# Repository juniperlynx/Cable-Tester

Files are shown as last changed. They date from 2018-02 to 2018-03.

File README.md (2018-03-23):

# Cable-Tester
This is a replacement PCB and software for a cheap commercial cable tester usually sold as the HL-486 (though there are other model numbers, mine is ST-M810).
It improves on the original design by adding beefier drive circuitry and a proper voltage regulator for the microcontroller.

Schematics and PCB layouts are available for both ends. The current revision of the Gerbers is untested but only contains slight variations from the most recently ordered version. Complete BOMs for both the master and remote ends are now available for both ends along with Digikey shoping carts in .csv format. I haven't been able to find a source for the multi-LED standoffs used to space the strand indicator LEDs so I've modeled a part in OpenSCAD. The OpenSCAD source and a rendered .stl file are available but untested at this time.

The original Kicad design files are in "Kicad Files/" and the software source code in "Software/".
If you'd like to build your own use the Gerber files in "Gerbers/" and the BOMs in "BOM/" along with the standoff model in "3D Parts/STL"

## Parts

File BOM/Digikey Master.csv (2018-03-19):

Manufacturer Part Number | Manufacturer | Digi-Key Part Number | Customer Reference | Reference Designator | Packaging | Part Status | Quantity | Unit Price | Extended Price | Quantity Available | Mfg Std Lead Time | Description | RoHS Status | Lead Free Status | REACH Status
SLR-342VR3F | Rohm Semiconductor | 511-1250-ND |  |  | Bulk | Active | 1 | 0.55000 | $0.55 | 44855 | 10 Weeks | LED RED DIFF 3MM ROUND T/H | RoHS Compliant | Lead free | REACH Unaffected
EG2301A | E-Switch | EG1944-ND |  |  | Bulk | Active | 1 | 0.80000 | $0.80 | 4235 | 11 Weeks | SWITCH SLIDE DP3T 200MA 30V | RoHS Compliant | Lead free | REACH Unaffected
5555154-1 | TE Connectivity AMP Connectors | A31440-ND |  |  | Tray | Active | 1 | 1.69000 | $1.69 | 1817 | 17 Weeks | CONN MOD JACK 6P6C R/A SHIELDED | RoHS Compliant | Lead free | Not Available
5555153-1 | TE Connectivity AMP Connectors | A31438-ND |  |  | Tray | Active | 1 | 1.42000 | $1.42 | 10974 | 17 Weeks | CONN MOD JACK 8P8C R/A SHIELDED | RoHS Compliant | Lead free | Not Available
LEDM-2-10 | Essentra Components | RPC4263-ND |  |  | Bulk | Active | 1 | 0.44000 | $0.44 | 5000 | 7 Weeks | LED SPACER 3MM T-1 BLACK 10MM | RoHS Compliant | Lead free | REACH Unaffected
M20-9720345 | Harwin Inc. | 952-1921-ND |  |  | Bulk | Active | 1 | 0.33000 | $0.33 | 1730 | 10 Weeks | 2X3POS DIL VERTICAL PIN HEADER | RoHS Compliant | Lead free | REACH Unaffected
UA78L05ACDR | Texas Instruments | 296-1364-1-ND |  |  | Cut Tape (CT) | Active | 1 | 0.50000 | $0.50 | 19285 | 6 Weeks | IC REG LINEAR 5V 100MA 8SOIC | RoHS Compliant | Lead free | REACH Unaffected
SSL-LX2573SRD | Lumex Opto/Components Inc. | 67-1049-ND |  |  | Bulk | Active | 9 | 0.46000 | $4.14 | 5202 | 12 Weeks | LED RED DIFF 5X2MM RECT T/H | RoHS Compliant | Lead free | REACH Unaffected
ATTINY24A-SSUR | Microchip Technology | ATTINY24A-SSURCT-ND |  |  | Cut Tape (CT) | Active | 1 | 0.76000 | $0.76 | 21974 | 4 Weeks | IC MCU 8BIT 2KB FLASH 14SOIC | RoHS Compliant | Lead free | REACH Unaffected
BSS84PH6433XTMA1 | Infineon Technologies | BSS84PH6433XTMA1CT-ND |  |  | Cut Tape (CT) | Active | 9 | 0.28000 | $2.52 | 31583 | Not Available | MOSFET P-CH 60V 170MA SOT-23 | RoHS Compliant | Lead free | REACH Unaffected
2N7002P,235 | Nexperia USA Inc. | 1727-1865-1-ND |  |  | Cut Tape (CT) | Active | 9 | 0.16000 | $1.44 | 92060 | 26 Weeks | MOSFET N-CH 60V 0.36A SOT-23 | RoHS Compliant | Lead free | REACH Unaffected
1N4448W-TP | Micro Commercial Co | 1N4448WTPMSCT-ND |  |  | Cut Tape (CT) | Active | 9 | 0.14000 | $1.26 | 448109 | 8 Weeks | DIODE GEN PURP 75V 250MA SOD123 | RoHS Compliant | Lead free | REACH Unaffected
CC0805KRX7R8BB104 | Yageo | 311-1141-1-ND |  |  | Cut Tape (CT) | Active | 1 | 0.10000 | $0.10 | 0 | 37 Weeks | CAP CER 0.1UF 25V X7R 0805 | RoHS Compliant | Lead free | REACH Unaffected
CC0805KKX7R8BB105 | Yageo | 311-1456-1-ND |  |  | Cut Tape (CT) | Active | 2 | 0.12000 | $0.24 | 492833 | 19 Weeks | CAP CER 1UF 25V X7R 0805 | RoHS Compliant | Lead free | REACH Unaffected
RC0805JR-0710KL | Yageo | 311-10KARCT-ND |  |  | Cut Tape (CT) | Active | 2 | 0.10000 | $0.20 | 4354256 | 23 Weeks | RES SMD 10K OHM 5% 1/8W 0805 | RoHS Compliant | Lead free | REACH Unaffected
RC0805JR-071KL | Yageo | 311-1.0KARCT-ND |  |  | Cut Tape (CT) | Active | 1 | 0.10000 | $0.10 | 3591832 | 23 Weeks | RES SMD 1K OHM 5% 1/8W 0805 | RoHS Compliant | Lead free | REACH Unaffected
RC0805JR-07200RL | Yageo | 311-200ARCT-ND |  |  | Cut Tape (CT) | Active | 9 | 0.10000 | $0.90 | 459061 | 23 Weeks | RES SMD 200 OHM 5% 1/8W 0805 | RoHS Compliant | Lead free | REACH Unaffected
232 | Keystone Electronics | 36-232-ND |  |  | Bulk | Active | 1 | 0.60000 | $0.60 | 62435 | 6 Weeks | STRAP BATT ECON 9V I STYLE 4"LD | RoHS Compliant | Lead free | REACH Unaffected

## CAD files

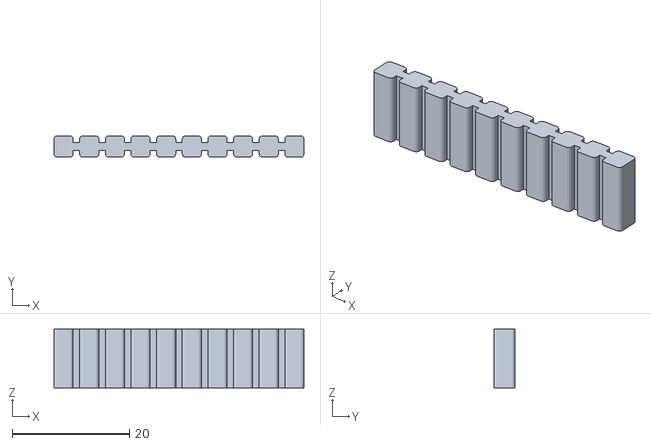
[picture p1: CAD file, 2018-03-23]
3D Parts/STL/LED standoff.stl
42.7 x 3.63 x 10.0

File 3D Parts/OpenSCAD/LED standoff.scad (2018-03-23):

$fn = 30;

// Produces dividers between LEDs, width and length are
// center-to-center for the bounding cylinders so total
// length is length + (edgeradius * 2) and the same for
// width. Height is as given though
module divider(width, length, height, edgeradius) {
    hull() {
        translate([-length/2, width/2, 0]) {
            cylinder(r = edgeradius, h = height);
        }
        translate([-length/2, -width/2, 0]) {
            cylinder(r = edgeradius, h = height);
        }
        translate([length/2, width/2, 0]) {
            cylinder(r = edgeradius, h = height);
        }
        translate([length/2, -width/2, 0]) {
            cylinder(r = edgeradius, h = height);
        }
    }
}
// Produces an LED standoff with the given number of
// spaces, spacing, width (center-to-center) and height.
module standoff(numspaces, spacing, width, voidsize, height){
    divlength = spacing - (voidsize * 2);
    supportwidth = width - voidsize;
    length = (numspaces * spacing) + divlength;
    union() {    
        for(i = [0:numspaces]) {
            translate([i * spacing, 0, 0]) { 
                divider(width, divlength, height, voidsize/2);
            }
        }
        translate([-divlength/2,-supportwidth/2,0]){
            cube([length,supportwidth,height]);
        }
    }
}
// Set parameters. The units here are in millimeters.

// Number of LEDs
numleds = 9;

// Spacing between LEDs
spacing = 4.3815;

// LED pad pitch
width = 2.54;

// LED pad drill diameter (plus some)
voidsize = 1.1;

// Standoff height
height = 10;

// Get part
standoff(numleds, spacing, width, voidsize, height);

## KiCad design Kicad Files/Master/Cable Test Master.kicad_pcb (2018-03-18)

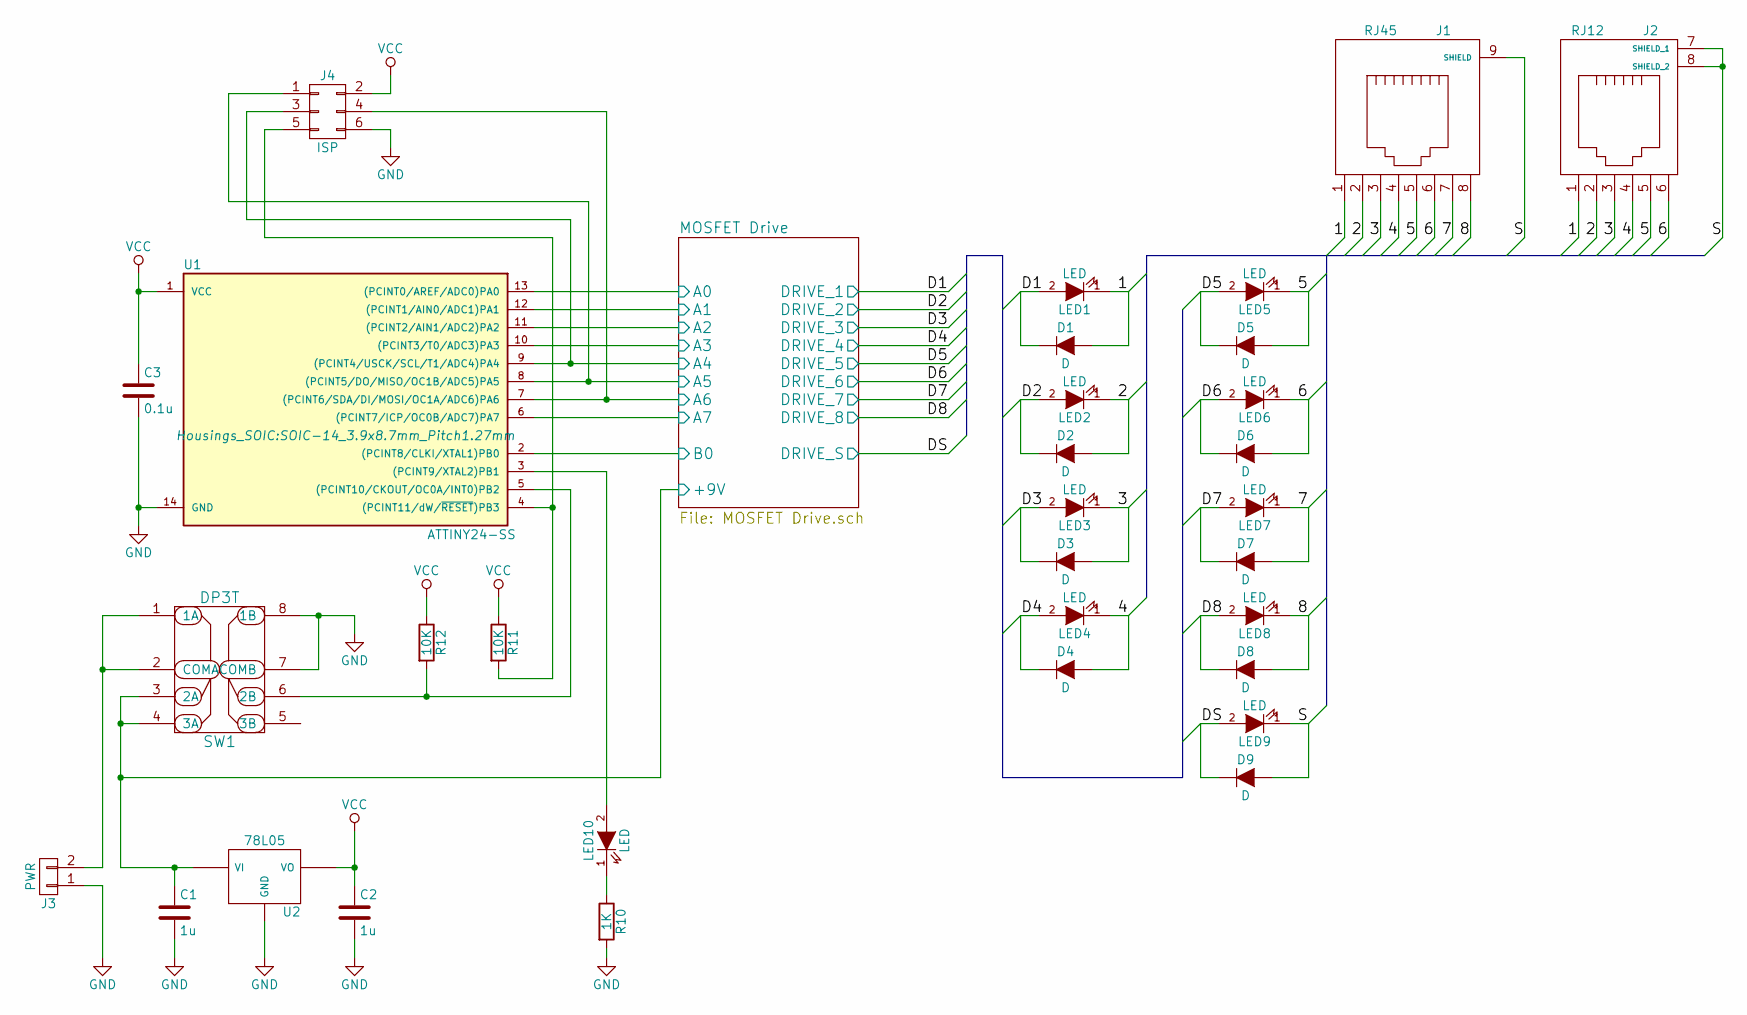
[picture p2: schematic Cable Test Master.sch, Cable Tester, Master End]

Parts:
C1, C2: 1u; C_0805_HandSoldering
C3: 0.1u; C_0805_HandSoldering
D1, D2, D3, D4, D5, D6, D7, D8, D9: D; SOD-123
J1: RJ45; RJ45_SHLD
J2: RJ12; RJ12_SHLD
J3: PWR; Pin_Header_Straight_1x02
J4: ISP; Pin_Header_Straight_2x03
LED1, LED2, LED3, LED4, LED5, LED6, LED7, LED8, LED9, LED10: LED; LED-3MM
R10: 1K; R_0805_HandSoldering
R11, R12: 10K; R_0805_HandSoldering
SW1: DP3T; SW_DP3T_SLIDE
U1: ATTINY24-SS; SOIC-14_3.9x8.7mm_Pitch1.27mm
U2: 78L05; 78L05_SOIC

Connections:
/1: D1.2 (A), J1.1, J2.1, LED1.1 (K)
/2: D2.2 (A), J1.2, J2.2, LED2.1 (K)
/3: D3.2 (A), J1.3, J2.3, LED3.1 (K)
/4: D4.2 (A), J1.4, J2.4, LED4.1 (K)
/5: D5.2 (A), J1.5, J2.5, LED5.1 (K)
/6: D6.2 (A), J1.6, J2.6, LED6.1 (K)
/7: D7.2 (A), J1.7, LED7.1 (K)
/8: D8.2 (A), J1.8, LED8.1 (K)
/MOSFET Drive/+9V: C1.1, SW1.3 (2A), SW1.4 (3A), U2.VI; also elsewhere on the board
/MOSFET Drive/A0: U1.13 ((PCINT0/AREF/ADC0)PA0); also elsewhere on the board
/MOSFET Drive/A1: U1.12 ((PCINT1/AIN0/ADC1)PA1); also elsewhere on the board
/MOSFET Drive/A2: U1.11 ((PCINT2/AIN1/ADC2)PA2); also elsewhere on the board
/MOSFET Drive/A3: U1.10 ((PCINT3/T0/ADC3)PA3); also elsewhere on the board
/MOSFET Drive/A4: J4.3, U1.9 ((PCINT4/USCK/SCL/T1/ADC4)PA4); also elsewhere on the board
/MOSFET Drive/A5: J4.1, U1.8 ((PCINT5/DO/MISO/OC1B/ADC5)PA5); also elsewhere on the board
/MOSFET Drive/A6: J4.4, U1.7 ((PCINT6/SDA/DI/MOSI/OC1A/ADC6)PA6); also elsewhere on the board
/MOSFET Drive/A7: U1.6 ((PCINT7/ICP/OC0B/ADC7)PA7); also elsewhere on the board
/MOSFET Drive/B0: U1.2 ((PCINT8/CLKI/XTAL1)PB0); also elsewhere on the board
/MOSFET Drive/DRIVE_1: D1.1 (K), LED1.2 (A); also elsewhere on the board
/MOSFET Drive/DRIVE_2: D2.1 (K), LED2.2 (A); also elsewhere on the board
/MOSFET Drive/DRIVE_3: D3.1 (K), LED3.2 (A); also elsewhere on the board
/MOSFET Drive/DRIVE_4: D4.1 (K), LED4.2 (A); also elsewhere on the board
/MOSFET Drive/DRIVE_5: D5.1 (K), LED5.2 (A); also elsewhere on the board
/MOSFET Drive/DRIVE_6: D6.1 (K), LED6.2 (A); also elsewhere on the board
/MOSFET Drive/DRIVE_7: D7.1 (K), LED7.2 (A); also elsewhere on the board
/MOSFET Drive/DRIVE_8: D8.1 (K), LED8.2 (A); also elsewhere on the board
/MOSFET Drive/DRIVE_S: D9.1 (K), LED9.2 (A); also elsewhere on the board
/S: D9.2 (A), J1.9 (SHIELD), J2.7 (SHIELD_1), J2.8 (SHIELD_2), LED9.1 (K)
GND: C1.2, C2.2, C3.2, J3.1, J4.6, R10.2, SW1.7 (COMB), SW1.8 (1B), U1.14 (GND), U2.GND; also elsewhere on the board
unnamed: J3.2, SW1.1 (1A), SW1.2 (COMA)
unnamed: J4.5, R11.2, U1.4 ((PCINT11/dW/~RESET~)PB3)
unnamed: LED10.1 (K), R10.1
unnamed: LED10.2 (A), U1.3 ((PCINT9/XTAL2)PB1)
unnamed: R12.2, SW1.6 (2B), U1.5 ((PCINT10/CKOUT/OC0A/INT0)PB2)
VCC: C2.1, C3.1, J4.2, R11.1, R12.1, U1.1 (VCC), U2.VO

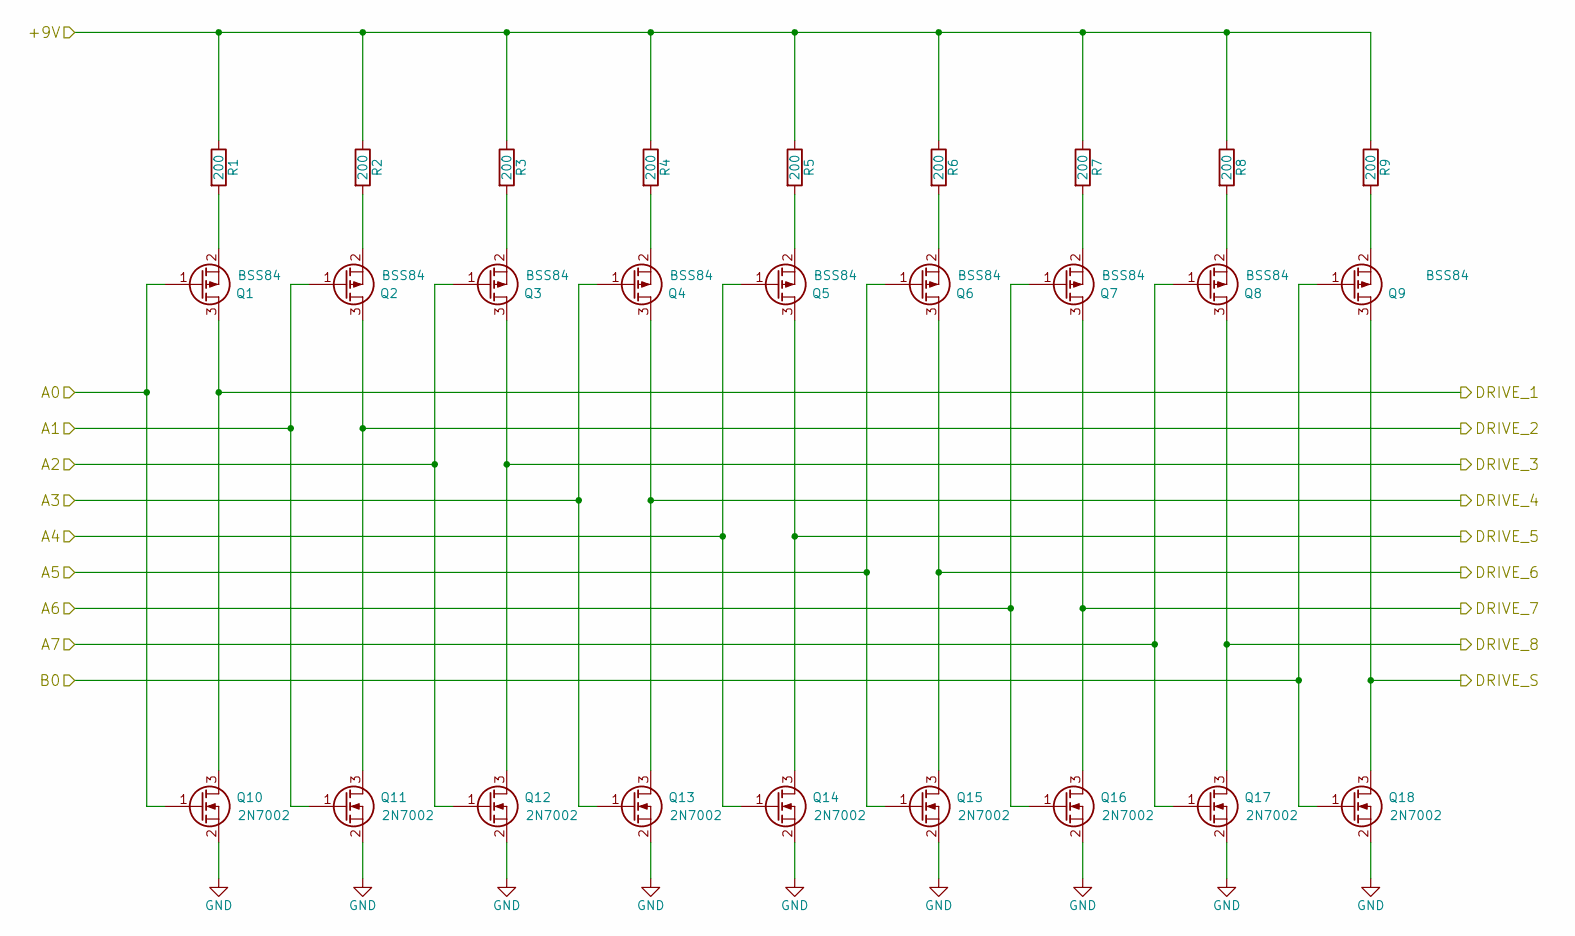
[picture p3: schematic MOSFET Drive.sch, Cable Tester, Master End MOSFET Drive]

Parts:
Q1, Q2, Q3, Q4, Q5, Q6, Q7, Q8, Q9: BSS84; SOT-23_Handsoldering
Q10, Q11, Q12, Q13, Q14, Q15, Q16, Q17, Q18: 2N7002; SOT-23_Handsoldering
R1, R2, R3, R4, R5, R6, R7, R8, R9: 200; R_0805_HandSoldering

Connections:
/MOSFET Drive/+9V: R1.1, R2.1, R3.1, R4.1, R5.1, R6.1, R7.1, R8.1, R9.1; also elsewhere on the board
/MOSFET Drive/A0: Q1.1 (G), Q10.1 (G); also elsewhere on the board
/MOSFET Drive/A1: Q2.1 (G), Q11.1 (G); also elsewhere on the board
/MOSFET Drive/A2: Q3.1 (G), Q12.1 (G); also elsewhere on the board
/MOSFET Drive/A3: Q4.1 (G), Q13.1 (G); also elsewhere on the board
/MOSFET Drive/A4: Q5.1 (G), Q14.1 (G); also elsewhere on the board
/MOSFET Drive/A5: Q6.1 (G), Q15.1 (G); also elsewhere on the board
/MOSFET Drive/A6: Q7.1 (G), Q16.1 (G); also elsewhere on the board
/MOSFET Drive/A7: Q8.1 (G), Q17.1 (G); also elsewhere on the board
/MOSFET Drive/B0: Q9.1 (G), Q18.1 (G); also elsewhere on the board
/MOSFET Drive/DRIVE_1: Q1.3 (D), Q10.3 (D); also elsewhere on the board
/MOSFET Drive/DRIVE_2: Q2.3 (D), Q11.3 (D); also elsewhere on the board
/MOSFET Drive/DRIVE_3: Q3.3 (D), Q12.3 (D); also elsewhere on the board
/MOSFET Drive/DRIVE_4: Q4.3 (D), Q13.3 (D); also elsewhere on the board
/MOSFET Drive/DRIVE_5: Q5.3 (D), Q14.3 (D); also elsewhere on the board
/MOSFET Drive/DRIVE_6: Q6.3 (D), Q15.3 (D); also elsewhere on the board
/MOSFET Drive/DRIVE_7: Q7.3 (D), Q16.3 (D); also elsewhere on the board
/MOSFET Drive/DRIVE_8: Q8.3 (D), Q17.3 (D); also elsewhere on the board
/MOSFET Drive/DRIVE_S: Q9.3 (D), Q18.3 (D); also elsewhere on the board
GND: Q10.2 (S), Q11.2 (S), Q12.2 (S), Q13.2 (S), Q14.2 (S), Q15.2 (S), Q16.2 (S), Q17.2 (S), Q18.2 (S); also elsewhere on the board
unnamed: Q1.2 (S), R1.2
unnamed: Q2.2 (S), R2.2
unnamed: Q3.2 (S), R3.2
unnamed: Q4.2 (S), R4.2
unnamed: Q5.2 (S), R5.2
unnamed: Q6.2 (S), R6.2
unnamed: Q7.2 (S), R7.2
unnamed: Q8.2 (S), R8.2
unnamed: Q9.2 (S), R9.2

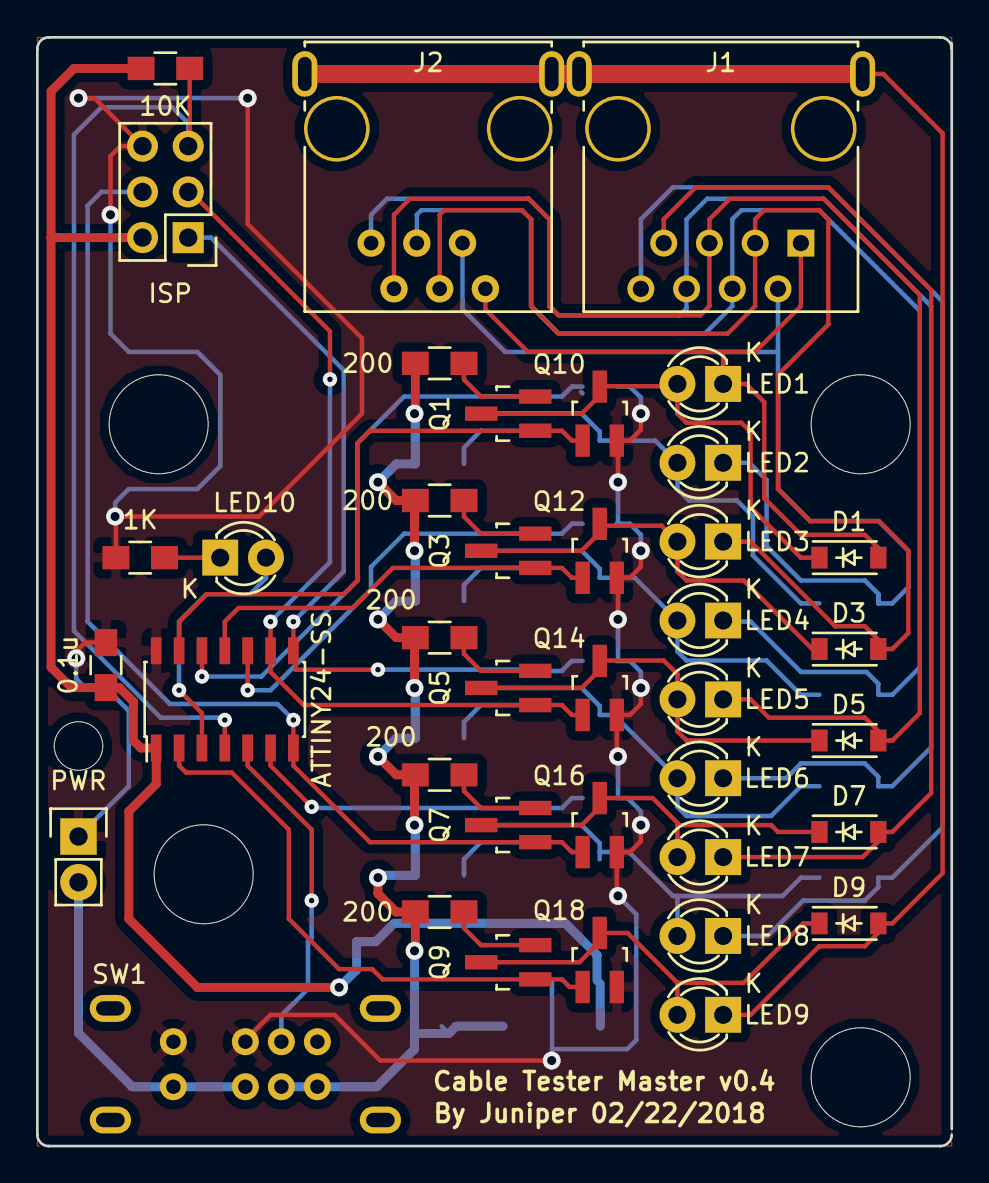
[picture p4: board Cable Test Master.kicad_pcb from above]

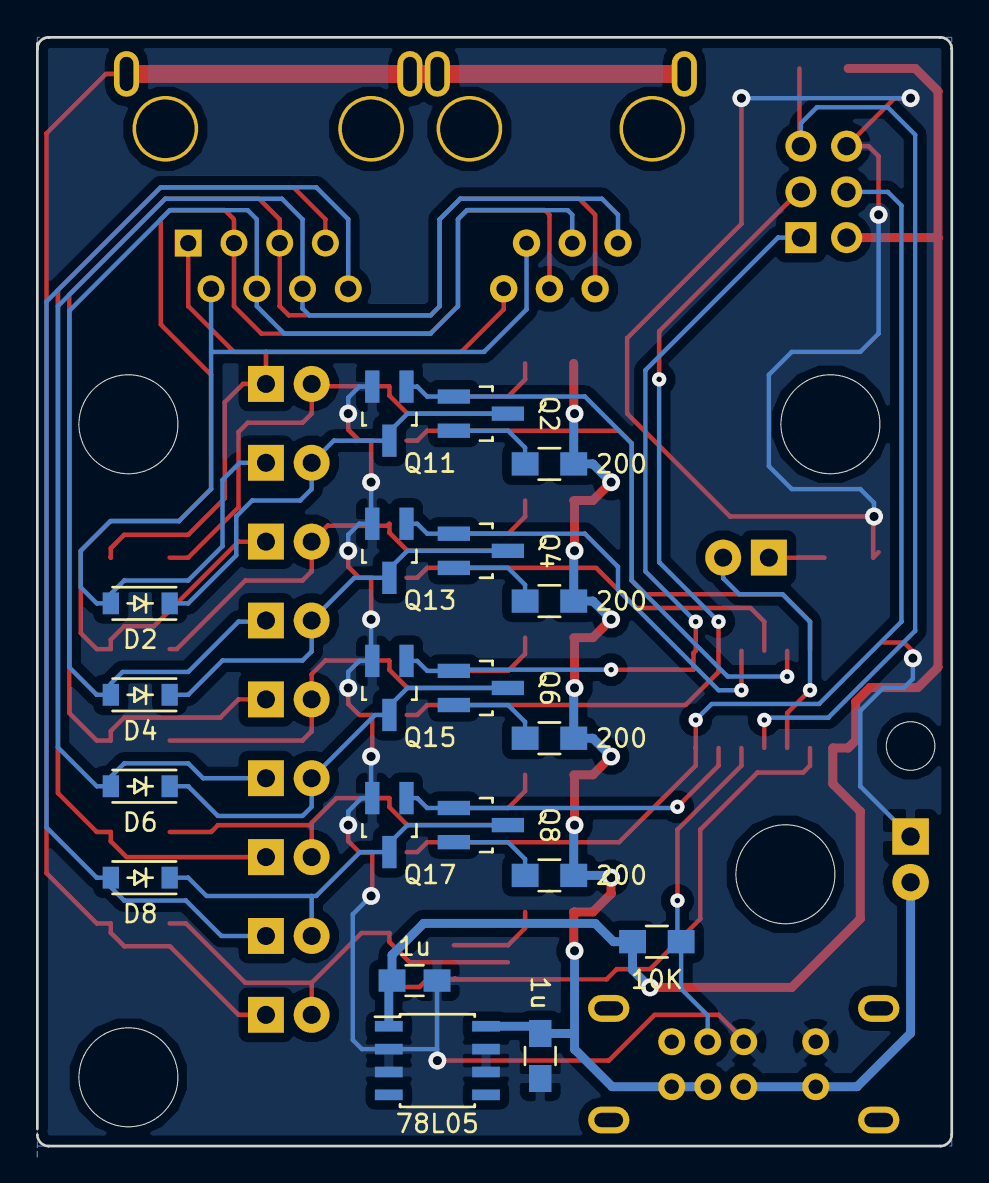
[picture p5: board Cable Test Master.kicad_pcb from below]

Board: 2 copper layers, 50.8 x 61.6 mm, 59 parts (20 on the bottom side), 44 nets.

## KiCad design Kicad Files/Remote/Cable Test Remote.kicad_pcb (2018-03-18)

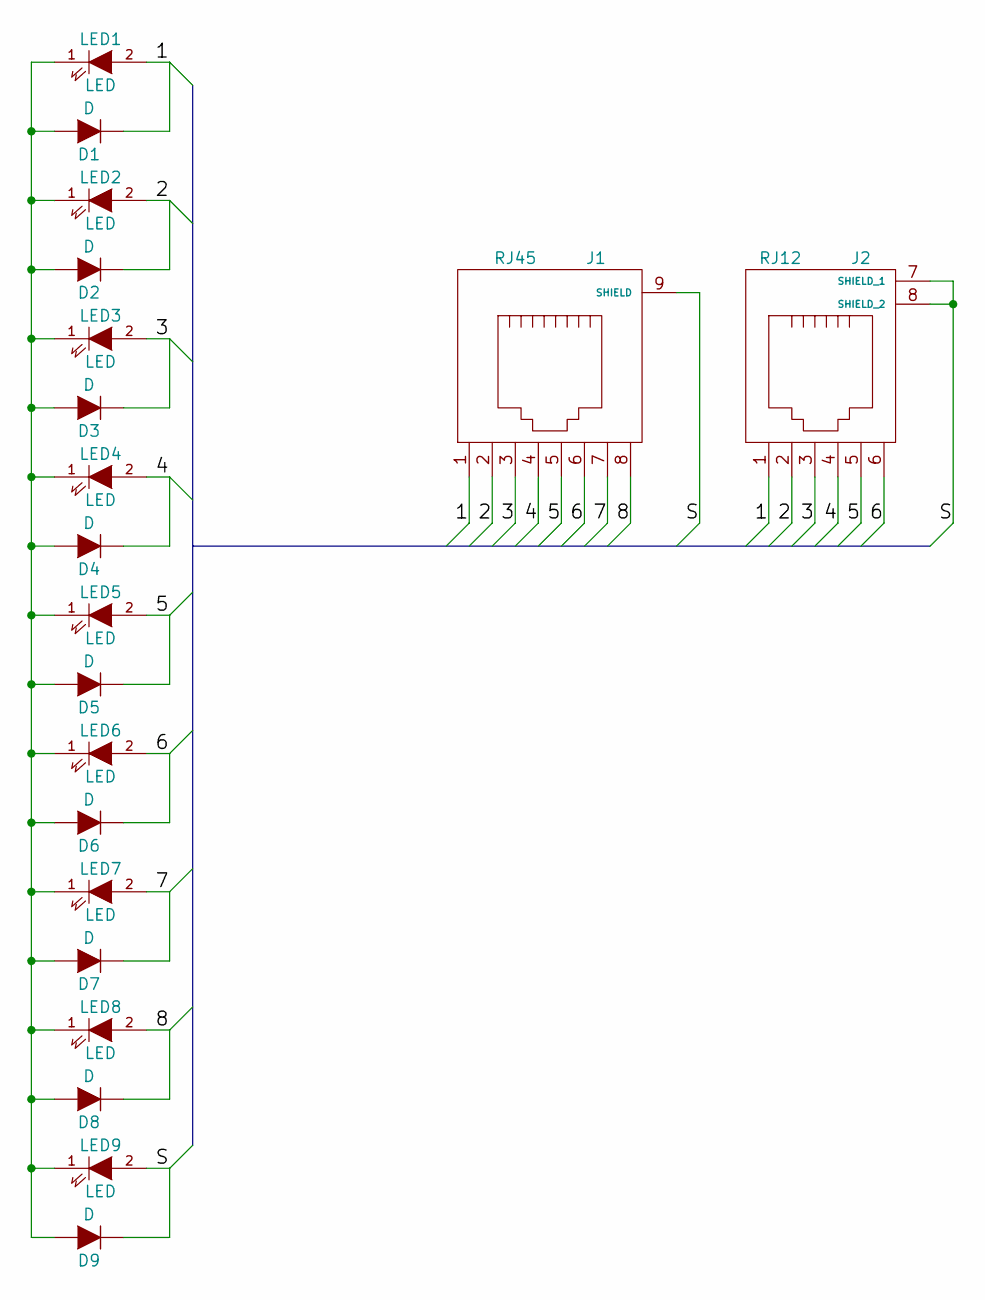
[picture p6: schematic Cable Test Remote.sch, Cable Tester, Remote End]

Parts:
D1, D2, D3, D4, D5, D6, D7, D8, D9: D; SOD-123
J1: RJ45; RJ45_SHLD
J2: RJ12; RJ12_SHLD
LED1, LED2, LED3, LED4, LED5, LED6, LED7, LED8, LED9: LED; LED-3MM

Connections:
/1: D1.1 (K), J1.1, J2.1, LED1.2 (A)
/2: D2.1 (K), J1.2, J2.2, LED2.2 (A)
/3: D3.1 (K), J1.3, J2.3, LED3.2 (A)
/4: D4.1 (K), J1.4, J2.4, LED4.2 (A)
/5: D5.1 (K), J1.5, J2.5, LED5.2 (A)
/6: D6.1 (K), J1.6, J2.6, LED6.2 (A)
/7: D7.1 (K), J1.7, LED7.2 (A)
/8: D8.1 (K), J1.8, LED8.2 (A)
/S: D9.1 (K), J1.9 (SHIELD), J2.7 (SHIELD_1), J2.8 (SHIELD_2), LED9.2 (A)
unnamed: D1.2 (A), D2.2 (A), D3.2 (A), D4.2 (A), D5.2 (A), D6.2 (A), D7.2 (A), D8.2 (A), D9.2 (A), LED1.1 (K), LED2.1 (K), LED3.1 (K), LED4.1 (K), LED5.1 (K), LED6.1 (K), LED7.1 (K), LED8.1 (K), LED9.1 (K)

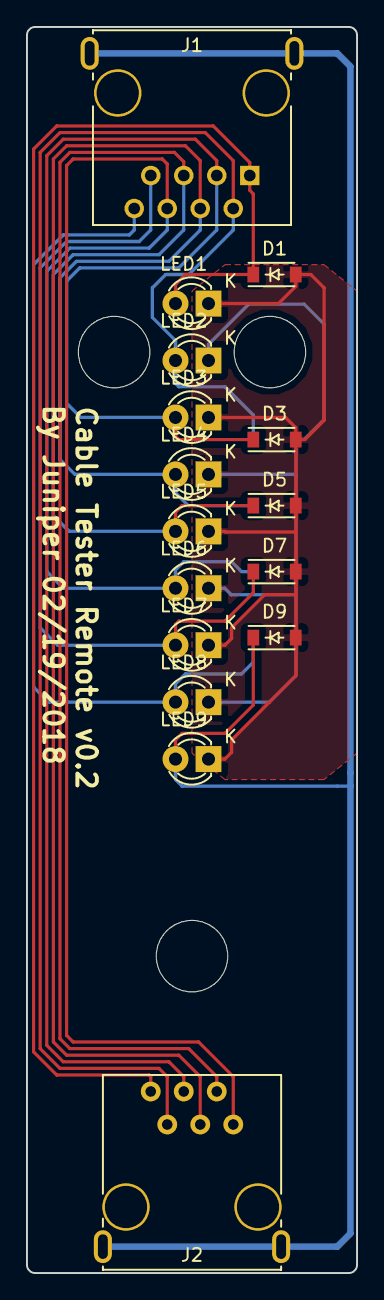
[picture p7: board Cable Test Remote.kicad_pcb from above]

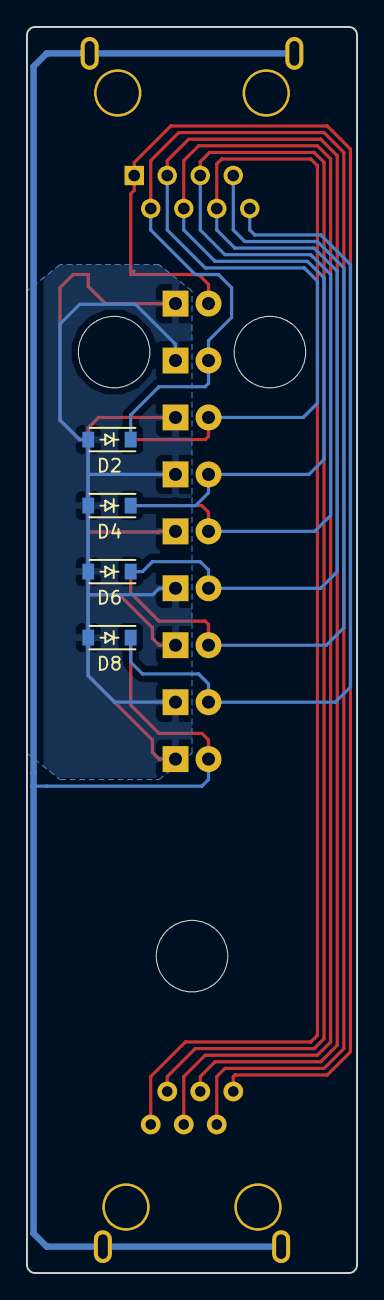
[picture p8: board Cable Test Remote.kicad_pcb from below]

Board: 2 copper layers, 25.4 x 95.9 mm, 20 parts (4 on the bottom side), 10 nets.

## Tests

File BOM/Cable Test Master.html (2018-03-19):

# Cable Tester, Master End BOM Rev 0.3

Date

# 2018-01-06

Ref

Qty

Value

Footprint

[C] -

C1 C2

2

1u

0805 SMD

C3

1

0.1u

0805 SMD

[D] -

D1 D2 D3 D4 D6 D7 D8 D9 D5

9

D

SOD-123

[J] -

J2

1

RJ12

Shielded RJ12 connector (TE Connectivity 5555154-1 or equivalent)

J1

1

RJ45

Shielded RJ45 connector (TE Connectivity 5555153-1 or equivalent)

J3

1

PWR

9V Battery Clip

J4

1

ISP

2x3 0.100 Pitch Pin Header

[LED] -

LED1 LED2 LED3 LED4 LED5 LED6 LED7 LED8 LED9

10

LED

5x2mm Rectangular LED

LED10

10

LED

3mm LED

[Q] -

Q10 Q11 Q12 Q13 Q14 Q15 Q16 Q17 Q18

9

2N7002

SOT-23

Q9 Q8 Q7 Q6 Q5 Q4 Q3 Q2 Q1

9

BSS84

SOT-23

[R] -

R10

1

1K

0805 SMD

R12 R11

2

10K

0805 SMD

R1 R2 R3 R4 R5 R6 R7 R8 R9

9

200

0805 SMD

[SW] -

SW1

1

DP3T

DP3T Slide Switch (E-Switch EG2301A or equivalent)

[U] -

U1

1

ATTINY24-SS

SOIC-14

U2

1

78L05

SOIC-8

[M] -

M1

1

Standoff

10mm LED standoff for 9 LEDs with 0.1725 in spacing

M2

1

Standoff

10mm T1 LED standoff (Essentra Components LEDM-2-10 or equivalent)

# BOM made with KICAD_BOM_WIZARD (https://github.com/HashDefineElectronics/KiCad_BOM_Wizard) (Generated Sun 11 Mar 2018 01:53:34 PM MDT)

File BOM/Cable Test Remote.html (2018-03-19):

# Cable Tester, Remote End BOM Rev 0.1

Date

# 2018-01-06

Ref

Qty

Value

Footprint

[D] -

D1 D2 D3 D4 D5 D6 D7 D8 D9

9

1N4448

SOD-123

[J] -

J2

1

RJ12

Shielded RJ12 connector (TE Connectivity 5555154-1 or equivalent)

J1

1

RJ45

Shielded RJ45 connector (TE Connectivity 5555153-1 or equivalent)

[LED] -

LED1 LED2 LED3 LED4 LED5 LED6 LED7 LED8 LED9

9

LED

5x2mm Rectangular LED

[M] -

M1

1

Standoff

10mm LED standoff for 9 LEDs with 0.1725 in spacing

# BOM made with KICAD_BOM_WIZARD (https://github.com/HashDefineElectronics/KiCad_BOM_Wizard) (Generated Thu 22 Feb 2018 08:11:45 PM MST)

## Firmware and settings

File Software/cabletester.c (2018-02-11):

// Firmware for a simple cable tester using the ATtiny 24/44/84
// By:   _           _               
//      (_)_  _ _ _ (_)_ __  ___ _ _ 
//      | | || | ' \| | '_ \/ -_) '_|
//     _/ |\_,_|_||_|_| .__/\___|_|  
//    |__/            |_|  
// Filename: cabletest.c
// Date: Feb 01, 2018

// Define CPU frequency for delay function (must be before delay.h include)
#define F_CPU 800000UL

// Include AVR I/O defines and the delay function
#include <avr/io.h>
#include <avr/interrupt.h>
#include <avr/sleep.h>
#include <util/delay.h>

// Define delay times, width of I/O ports, speed modes, and number of conductors to test
#define SLOW_PRESCALE _BV(WDP2) | _BV(WDP1)
#define FAST_PRESCALE _BV(WDP2) | _BV(WDP0)
#define SLOW_MODE 1
#define FAST_MODE 2
#define BLINK_DELAY 50
#define NUM_CONDUCTORS 9

// Declare state and mode variables
volatile int state = 0;
volatile int mode = SLOW_MODE;

// Sets up data direction register
void testerInit(void) {
    // Set PORTA and PORTB 0 & 1 to output and PORTB2 to input
    DDRA = (1 << 8) - 1; 
    DDRB = (_BV(DDB0) | _BV(DDB1)) & ~_BV(DDB2);

    // Set watchdog prescaler to slow mode
    WDTCSR |= SLOW_PRESCALE;

    // Enable watchdog interrupts
    WDTCSR |= _BV(WDIE);

    // Enable Interrupts
    sei();

    // Set sleep mode to power off
    set_sleep_mode(SLEEP_MODE_PWR_DOWN);

    // Disable ADC before shutdown
    ADCSRA &= ~_BV(ADEN);

    // Shutdown ADC, USI, and timers for power savings
    PRR |= _BV(PRADC) | _BV(PRUSI) | _BV(PRTIM1) | _BV(PRTIM0);
}

// Sets cable tester output pins to binary number given as pinState
void testerOut(int pinState) {
    // Bottom half of pinState to PORTA, top to PORTB
    PORTA = ~(pinState & ((1 << 8) - 1));
    PORTB = (PORTB | _BV(PB0)) & ~((pinState & (1 << 8)) >> 8);
}

// Blinks the Activity light on the cable tester for the specified time
// Note that holdTime must be available at compile time due to limitations
// within _delay_ms()
void testerBlink() {
        // Toggle PORTB1
        PORTB |= _BV(PB1);
        _delay_ms(BLINK_DELAY);
        PORTB &= ~_BV(PB1);
}

// Returns Nonzero if in slow mode and zero in fast mode
int testerModeSlow() {
    return PINB & _BV(PB2);
}

// Change WDTCSR Prescaler to WDP3-0 (bits 5 and 2-0) in newWDTCSR
// See section 8.4 in the ATtiny24/44/84 datasheet
void changeWDTPrescale(int newWDTCSR) {
    // Declare temporary WDTCSR value
    int tempWDTCSR;
 
    // Clear unused bits in WDTCSR and save as tempWDTCSR2
    // Then compute new WDTCSR from newWDTCSR and tempWDTCSR2
    tempWDTCSR = WDTCSR & ~(_BV(WDCE) | _BV(WDP3) | _BV(WDP2) | _BV(WDP1) | _BV(WDP0));
    tempWDTCSR |= (newWDTCSR & (_BV(WDP3) | _BV(WDP2) | _BV(WDP1) | _BV(WDP0)));


    // Write new WDTCSR
    WDTCSR = tempWDTCSR;
}

// Watchdog Timer ISR
ISR(WDT_vect) {
    // Output current state
    testerOut(1 << state);
        
    // Blink activity led
    testerBlink();

    // Increment state and iterate for each conductor tested
    state++;
    if (state >= NUM_CONDUCTORS) {
        state = 0;
    }

    // Check if running fast or slow
    // and wait till next cycle
    if (testerModeSlow() && mode != SLOW_MODE) {
        changeWDTPrescale(SLOW_PRESCALE);
        mode = SLOW_MODE;
    }
    else if (!testerModeSlow() && mode != FAST_MODE) {
        changeWDTPrescale(FAST_PRESCALE);
        mode = FAST_MODE;
    }
}


// The main program
int main (void) {
    // Set data direction, interrupts, and sleep mode
    testerInit();

    // Go to sleep and wait for interrupts
    while(1) {
        sleep_mode();
    }
}

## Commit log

2018-02-03 Remove unnecessary files
    [2018-01-17T23_00_05.csv]
2018-02-03 Change Folder Structure
    [Cable Test Master-B.Cu.gbl, Cable Test Master-B.Mask.gbs, Cable Test Master-B.SilkS.gbo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]
2018-02-04 Add BOM
2018-02-10 Fix mounting holes and RJ12 footprint
    [Cable Test Master.kicad_pcb]
2018-02-10 Update Gerbers to reflect fixes
    [Cable Test Master-B.Cu.gbl, Cable Test Master-B.Mask.gbs, Cable Test Master-B.SilkS.gbo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]
2018-02-11 Fix P-channel MOSFET wiring and software output levels
    [Cable Test Master.kicad_pcb, MOSFET Drive.sch]
2018-02-16 Improve fit and finish issues
    [Cable Test Master.kicad_pcb, Cable Test Master.sch]
2018-02-16 Begin PCB layout
    [Cable Test Remote.sch]
2018-02-17 Update Component Positioning on Master PCB
    Updates the positioning of components to fix positioning issues introduced
    by the earlier shortening of the board to improve fit.
    [Cable Test Master.kicad_pcb, Cable Test Remote.kicad_pcb]
2018-02-17 Perform initial trace routing for remote end PCB
    Adds traces to PCB design for the remote end of the cable tester.
    [Cable Test Remote.kicad_pcb]
2018-02-20 Adjust trace width and add text to remote end PCB
    [Cable Test Remote.kicad_pcb]
2018-02-23 Change R1-R9 to 100 ohm
    [Cable Test Master.kicad_pcb, Cable Test Master.sch, MOSFET Drive.sch]
2018-02-23 Update BOM for master end
2018-02-23 Generate initial remote end BOM
2018-02-24 Generate Gerbers for remote end
    [Cable Test Remote-B.Cu.gbl, Cable Test Remote-B.Mask.gbs, Cable Test Remote-B.SilkS.gbo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]
2018-02-24 Update Gerbers for master end to v0.3
    [Cable Test Master-B.Cu.gbl, Cable Test Master-B.Mask.gbs, Cable Test Master-B.SilkS.gbo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]
2018-02-24 Fix revision printing on PCB
    [Cable Test Master.kicad_pcb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]
2018-03-11 Change SW2 reference to SW1
    [Cable Test Master.kicad_pcb, Cable Test Master.sch]
2018-03-11 Change current limiting resistors to 200 Ohm
    The 100 Ohm resistors worked but the LEDs burn rather bright. Increasing resistance to be easier on eyes. Also changed BOM to match.
    [Cable Test Master.kicad_pcb, MOSFET Drive.sch]
2018-03-11 Shorten Remote board to better fit case
    [Cable Test Remote.kicad_pcb]
2018-03-11 Update Gerbers to reflect changes
    [Cable Test Master-B.Cu.gbl, Cable Test Master-B.Mask.gbs, Cable Test Master-B.SilkS.gbo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]
2018-03-18 Fix small measurement error in RJ-12 Footprint
    [Cable Test Master.kicad_pcb, Cable Test Remote.kicad_pcb]
2018-03-18 Fix small measurement error in RJ-45 Footprint
    [Cable Test Master.kicad_pcb, Cable Test Remote.kicad_pcb]
2018-03-19 Fix footprint issues in Gerbers
    [Cable Test Master-B.Cu.gbl, Cable Test Master-B.Mask.gbs, Cable Test Master-B.SilkS.gbo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]
2018-03-19 Added Digikey carts to BOM
    [Digikey Master.csv, Digikey Remote.csv]
2018-03-19 Add 9V battery clip to Digikey Cart
    [Digikey Master.csv]
2018-03-23 Add 3d files for multi-LED standoff
    [LED standoff.scad, LED standoff.stl]
